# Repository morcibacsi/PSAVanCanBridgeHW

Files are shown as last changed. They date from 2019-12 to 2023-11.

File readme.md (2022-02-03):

# PSA VAN-CAN protocol bridge (hardware)

### What is it ?
This is the hardware needed for my PSA VAN-CAN protocol bridge software.

The files were created with KiCad. 

### v1.4

This is actually the sixth revision of the hardware (the fourth was faulty again and the fifth didn't make it to production).

It was designed as a shield for the ESP32 dev board. It uses the ESP32's RMT peripheral to read, the TSS463C to write the VAN bus and the CAN peripheral for connecting to the CAN bus. The CAN transceiver used on this board is the MCP2551.
The board was designed in a way that the LM7805 can be easily replaced by a step down converter shield.
To have an easier build I used a pre-built level shifter. I know it is not the best approach, but if I'd have it included on the board it would have been larger and much harder to build. My goal was to have a board which is easy to assemble.

I have included a buzzer and a DS18B20 thermometer on the board but they weren't ever tested if they work. I also included some spare connection points for later use.

If you are planning to build the board, go with the minimal setup. It is quite well tested, and is proven to work for years. The full board has never been tested. 

💡 **Make sure you don't populate R3 and R4 resistors as installing those cause errors in the car and the board won't work!**

### PCB

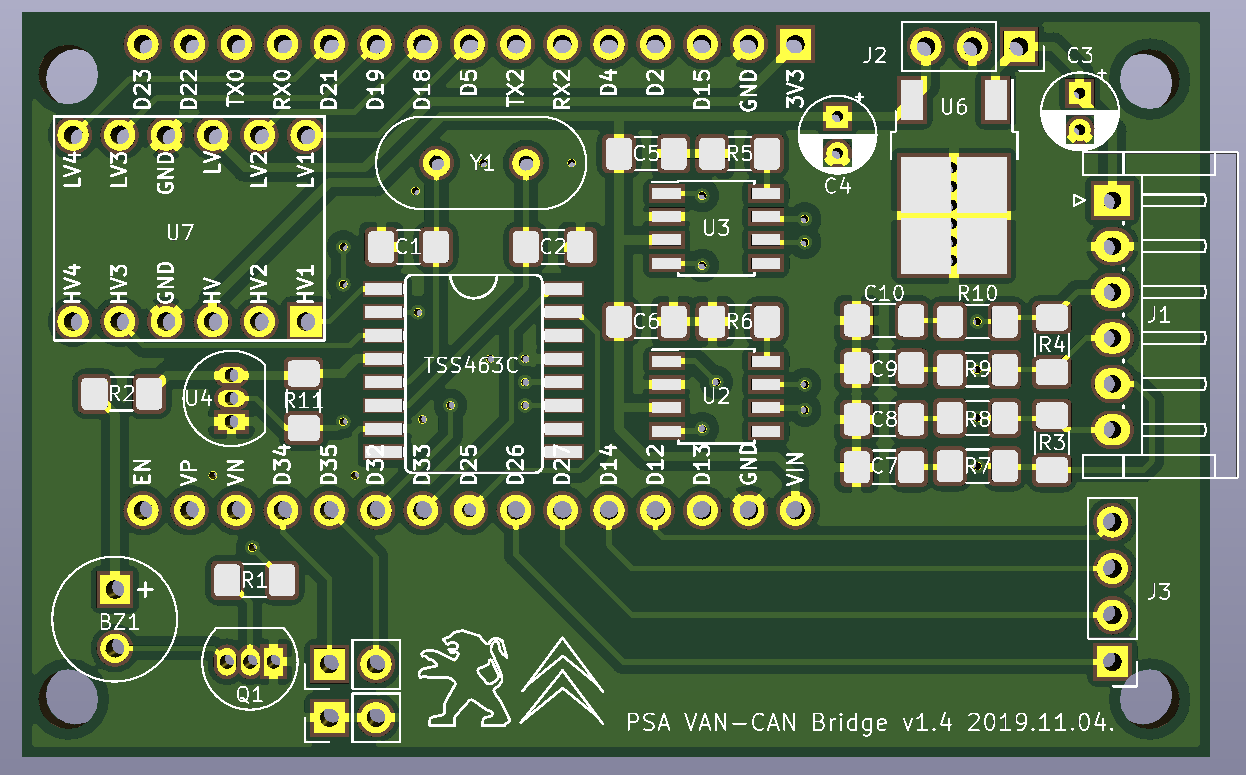
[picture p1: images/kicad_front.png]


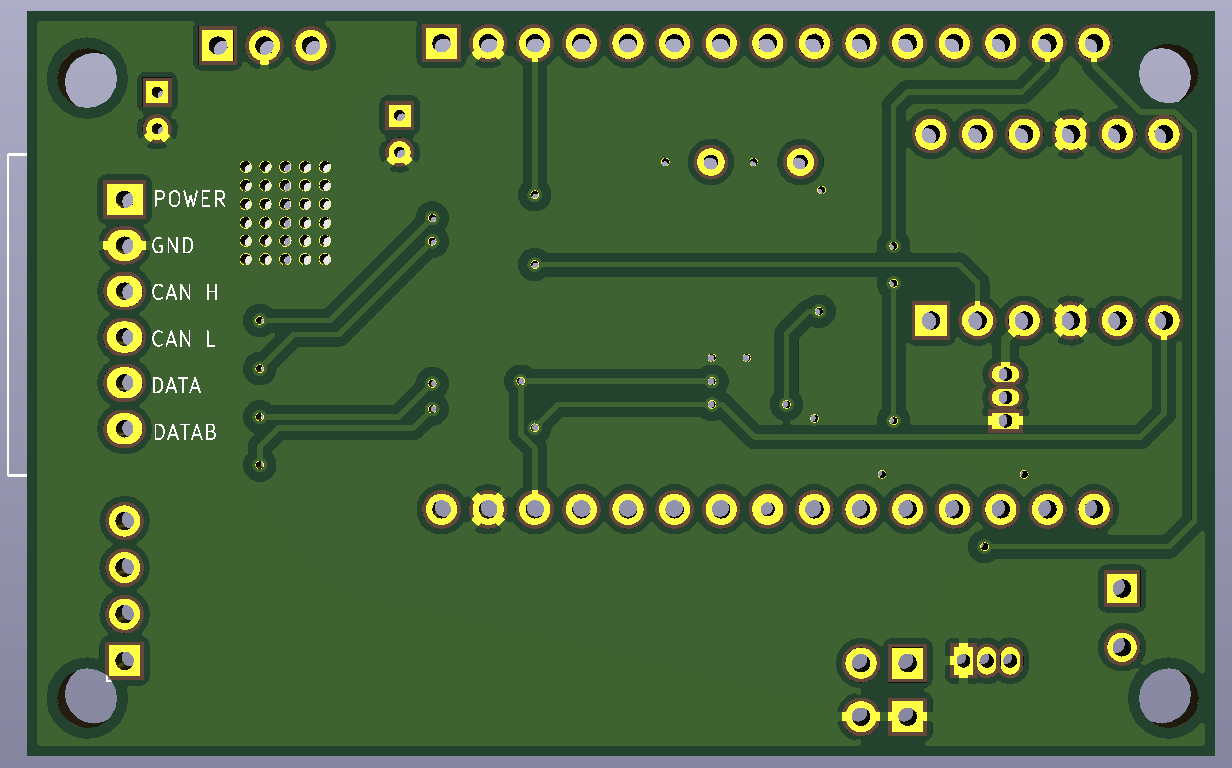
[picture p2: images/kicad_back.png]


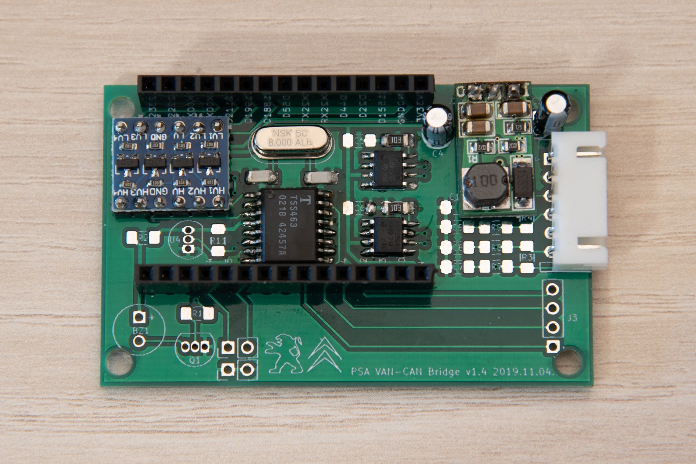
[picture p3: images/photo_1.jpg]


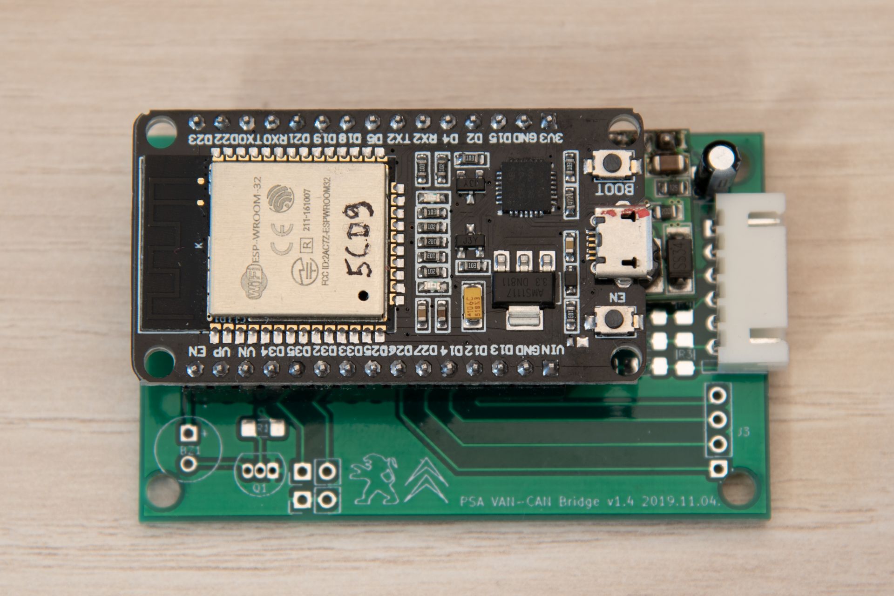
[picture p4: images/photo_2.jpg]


### BOM

### The absolute minimum to have it working:

| Ref | Quantity | Value |Footprint |
|-|-|-|-|
| C1 C2 | 2 | 22pF |Capacitor_SMD:C_1206_3216Metric_Pad1.42x1.75mm_HandSolder |
| C3 | 1 | 0.33uF |Capacitor_THT:CP_Radial_D4.0mm_P2.00mm |
| C4 | 1 | 0.1uF |Capacitor_THT:CP_Radial_D4.0mm_P2.00mm |
| Y1 | 1 | 8MHz |Crystal:Crystal_HC49-4H_Vertical |
| U1 | 1 | TSS463C |PSAVanCanBridge_v14:SO16L |
| U2 U3 | 2 | MCP2551-I-SN |Package_SO:SOIC-8_3.9x4.9mm_P1.27mm |
| U6 | 1 | LM7805_TO220 |Package_TO_SOT_SMD:TO-252-2 |
| U7 | 1 | LevelShifter4Shield |PSAVanCanBridge_v14:LevelShifter4_shield |
| R6 R5 | 2 | 10K |Resistor_SMD:R_1206_3216Metric_Pad1.42x1.75mm_HandSolder |
| J1 | 1 | Conn_01x06_Male |Connector_JST:JST_EH_S06B-EH_1x06_P2.50mm_Horizontal |

### The full board:

| | |
|-|-|
|Total Number of Parts | 36|
|Total Unique Parts | 22|

| Ref | Quantity | Value |Footprint |
|-|-|-|-|
| BZ1 | 1 | Buzzer |Buzzer_Beeper:MagneticBuzzer_Kingstate_KCG0601 |
| C1 C2 | 2 | 22pF |Capacitor_SMD:C_1206_3216Metric_Pad1.42x1.75mm_HandSolder |
| C3 | 1 | 0.33uF |Capacitor_THT:CP_Radial_D4.0mm_P2.00mm |
| C4 | 1 | 0.1uF |Capacitor_THT:CP_Radial_D4.0mm_P2.00mm |
| C6 C5 | 2 | 0.1uF |Capacitor_SMD:C_1206_3216Metric_Pad1.42x1.75mm_HandSolder |
| C8 C10 C7 C9 | 4 | 560pF |Capacitor_SMD:C_1206_3216Metric_Pad1.42x1.75mm_HandSolder |
| J1 | 1 | Conn_01x06_Male |Connector_JST:JST_EH_S06B-EH_1x06_P2.50mm_Horizontal |
| J2 | 1 | Conn_01x03_Male |Connector_PinSocket_2.54mm:PinSocket_1x03_P2.54mm_Vertical |
| J3 | 1 | Conn_01x04_Male |Connector_PinHeader_2.54mm:PinHeader_1x04_P2.54mm_Vertical |
| J4 J5 | 2 | Conn_01x02_Male |Connector_PinHeader_2.54mm:PinHeader_1x02_P2.54mm_Vertical |
| Q1 | 1 | PN2222A |Package_TO_SOT_THT:TO-92_Inline |
| R6 R5 | 2 | 10K |Resistor_SMD:R_1206_3216Metric_Pad1.42x1.75mm_HandSolder |
| R11 | 1 | 4.7K |Resistor_SMD:R_1206_3216Metric_Pad1.42x1.75mm_HandSolder |
| R3 R4 | 2 | 120 |Resistor_SMD:R_1206_3216Metric_Pad1.42x1.75mm_HandSolder |
| R2 R1 | 2 | 2.2K |Resistor_SMD:R_1206_3216Metric_Pad1.42x1.75mm_HandSolder |
| R8 R10 R7 R9 | 4 | 100 |Resistor_SMD:R_1206_3216Metric_Pad1.42x1.75mm_HandSolder |
| U1 | 1 | TSS463C |PSAVanCanBridge_v14:SO16L |
| U2 U3 | 2 | MCP2551-I-SN |Package_SO:SOIC-8_3.9x4.9mm_P1.27mm |
| U6 | 1 | LM7805_TO220 |Package_TO_SOT_SMD:TO-252-2 |
| U5 | 1 | ESP32 |PSAVanCanBridge_v14:ESP32_shield |
| U7 | 1 | LevelShifter4Shield |PSAVanCanBridge_v14:LevelShifter4_shield |
| U4 | 1 | DS18B20 |Package_TO_SOT_THT:TO-92_Inline |
| Y1 | 1 | 8MHz |Crystal:Crystal_HC49-4H_Vertical |

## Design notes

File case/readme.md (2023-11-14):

# PSA VAN-CAN protocol bridge (hardware) 3D printed case

### 3D printed case model
This is the 3D model for PSAVanCanBridge adapter in minimal hardware configuration.
Model contains two files:
- cap.stl
- body.stl

Cap is just press connection. For PCB mount I used M2.5x8 screws.

### Print details

I printed this on cheap chinese Ender 3 printer. Material is Devil Design PETG. Hotend temperature 230°C, table 70°C.

### Model look

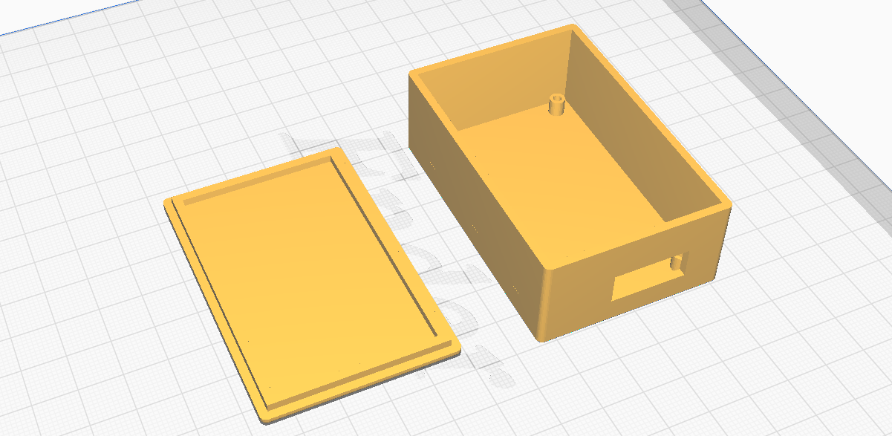
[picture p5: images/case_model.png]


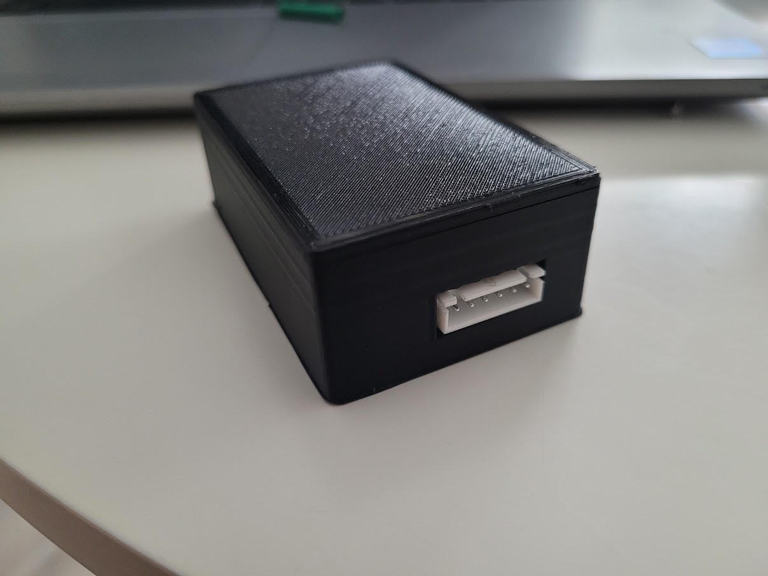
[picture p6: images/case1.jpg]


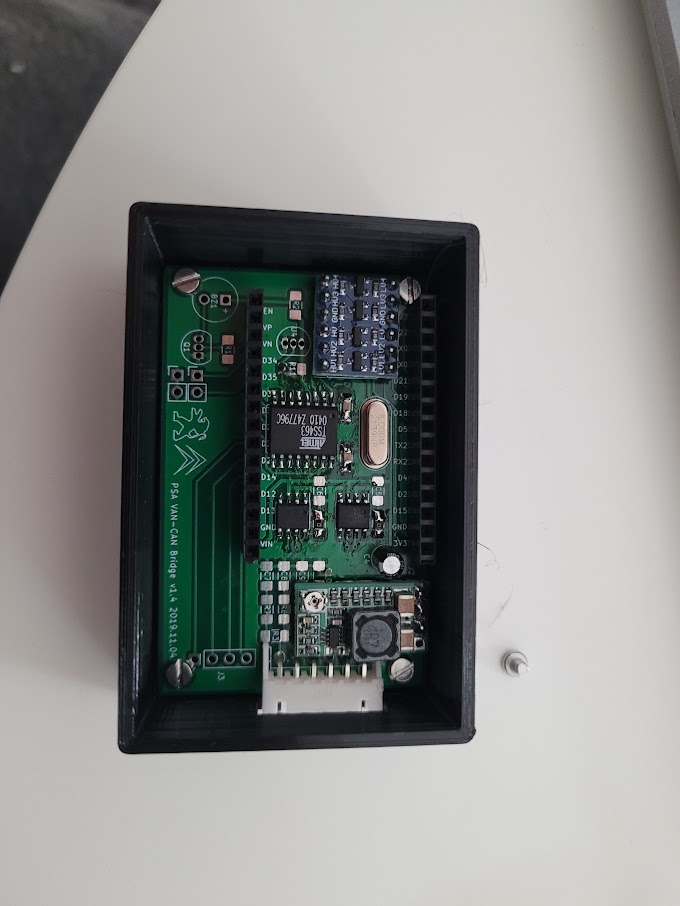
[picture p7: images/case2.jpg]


PS. It's simple case and my first CAD project. Hope someone will develop it ;)

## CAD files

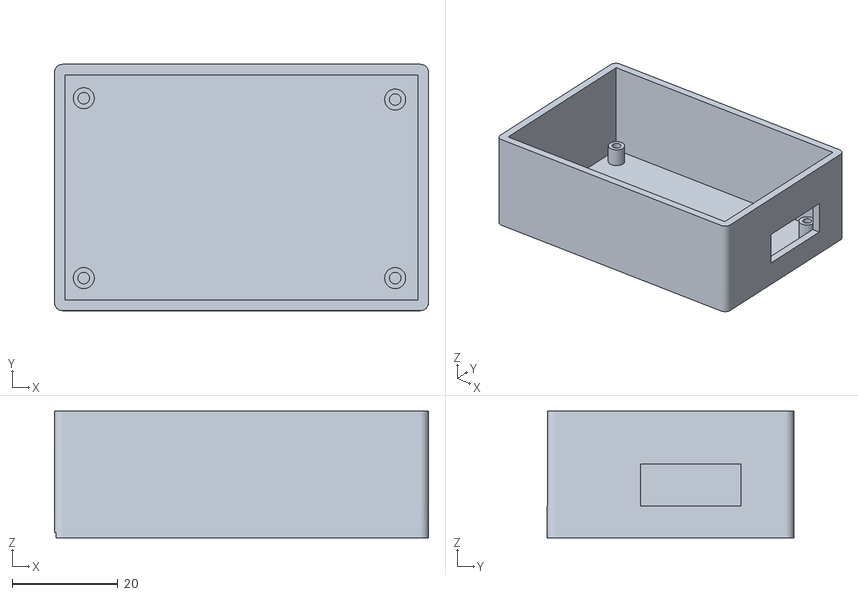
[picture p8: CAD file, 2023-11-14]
case/body.stl
70.8 x 46.6 x 24.0

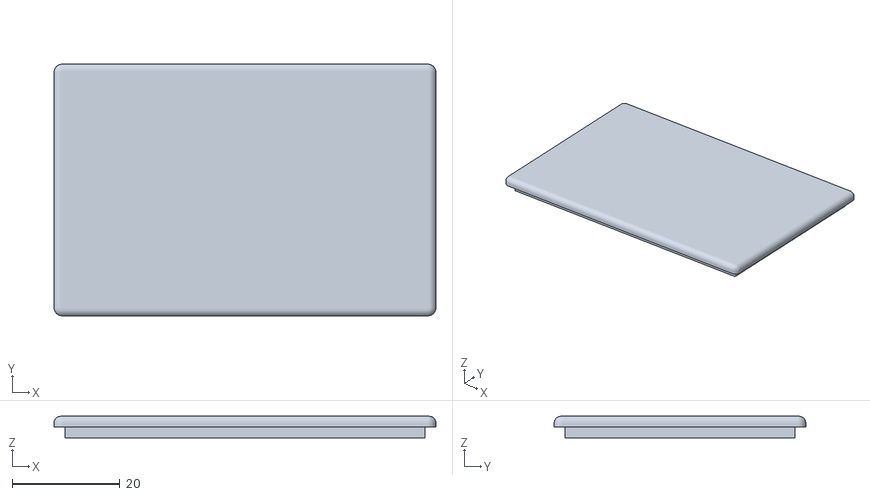
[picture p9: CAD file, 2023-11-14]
case/cap.stl
70.8 x 46.6 x 4.00

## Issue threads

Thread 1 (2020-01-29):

for better read/send message

unobayu, 2020-01-29:
after some trial. the hardware fail to read van bus data. also some problem (reboot) when send data. after measuring the data line in the car,there already have resistance. so i have to remove terminating resistor in the both tranceiver. now the hw11 is working good

morcibacsi, 2020-01-30:
Glad you make it work. I suggest to start with the setup what can be seen on the photos as I used it like that in my car. It is easier to add components later anyways than removing them.

DenGorobets, 2020-02-27:
Hi, can you answer a few questions?
I also have a VAN multimedia bus on my 2004 car. The head unit has a QUADLOCK connector (not ISO) and an on-board computer display with a 6-pin connector. I bought an Android device to replace the head unit, which in the kit has a Raise CAN emulator. When connected, of course, nothing works due to different buses. Will your device allow the full functioning of the Android device? And is it necessary to buy an on-board computer display that works on the CAN-bus?

morcibacsi, 2020-02-27:
@DenGorobets This means you have a monochrome RT3 navigation system. If you remove your original head unit, unfortunately that display will stop working. This is because those systems are a little bit funny: The RT3 communicates on the VAN bus however the display has a CAN bus connection towards the head unit. So the RT3 is translating the VAN bus packets for the display. But reverse engineering the CAN communication for that display would be a pain (I've tried it, but it just doesn't worth the effort). So in my opinion it is easier to just replace the display with a newer one. The navigation part would stop working anyways without the RT3. I assume you would like to keep the remote stalk function for your new Android head unit. My device is capable of translating the VAN bus packet of the remote stalk to the corresponding CAN packet. So if you would set the correct car type (Peugeot with CAN bus) in your Android system then most probably it would work.

DenGorobets, 2020-02-27:
Thank you for the explanation. Android device does not start when the ignition is turned on. If I understand correctly, it’s all because the CAN emulator does not understand that when you turn the key on the VAN bus, a command is sent to turn on the head unit, which the emulator does not understand.
Based on your answer, it is possible without using your development to connect the on-board computer display from the Peugeot 407, which will be controlled by the CAN emulator of the Android device. Right?

morcibacsi, 2020-02-27:
> Android device does not start when the ignition is turned on

Well that is another problem then. These aftermarket devices don't need ignition signal to work. If you connect to a power supply it should even turn on outside a car. What is the exact model number of the device?

> Based on your answer, it is possible without using your development to connect the on-board computer display from the Peugeot 407, which will be controlled by the CAN emulator of the Android device. Right?

Not quite. If you would like to install a display from a 407 then you definitely need my VAN-CAN bridge. The CAN device inside the Android head units don't send the data for those displays to boot up.

DenGorobets, 2020-02-27:
There is no exact name, I bought it at this link: https://aliexpress.ru/item/33035372080.html?spm

There are two connection cables in the kit: from ISO to 16 pin in an Android device, from QUADLOCK to 16 pin in an Android device.
In both cases, there are three wires to power the device: black - ground, yellow - permanent + 12V and red - when applying + 12V to the red wire, the device starts up (if you remove the device from the red + 12V, it falls asleep after 30 seconds).
In the adapter with ISO, the red cable is connected directly to the Android device.
In the adapter with QUADLOCK, the red cable is connected from the CAN emulator to the Android device.
Based on this, I suggested that it is the KAN emulator that launches the Android device when the ignition is turned on.

I do not exclude the option that the emulator is not working, there is no way to check it.

morcibacsi, 2020-02-27:
I see now. That quadlock connector you got with your Android device is for cars made after 2005 with CAN bus. In those cars there is no switched 12V in the quadlock connector, so most probably in those cars ignition signal from the CAN bus is used to turn on the device. For you the simplest thing would be to connect the red cable to the VAN+ pin which is I believe the A9 pin on the quadlock. That way your android unit would boot up when you open the car. And would go to sleep after a few minutes when you close it.

DenGorobets, 2020-02-27:
This is a great option for the first time. Thank you so much for the consultation!

Closed 2020-02-28.

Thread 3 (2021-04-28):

Bonjour

Mokrane82, 2021-04-28:
J'ai peugeot 307 année 2005 commande au volant autoradio RT3 VAN
J'ai acheté un autoradio android junsun 2G 32G B commande au volant.
J'ai utilisé 4 CANBUS
Mais il fonctionne pas

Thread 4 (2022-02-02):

Wont turn on. Issue with termination resistors

najdanovicivan, 2022-02-02:
When 120 ohm termination resistors are present on ether CAN or VAN line things will not work

VAN issue - The instrument gauge started to flicker all indicators turns on same way like the VAN line is disconnected
CAN issue - The screen does not turn on and RD45 will just spin CD motor for a fraction of second and this will happen in loop

I resolved the issue by removing  R3 and R4 resistors.

Tested with RD45 on 206CC

morcibacsi, 2022-02-03:
Thanks for reporting. It was known before, I just forgot to update the readme with the information. Added a warning in 14ef456b4231d8f84fe3717f5a421d99a402b76a

Closed 2022-02-03.

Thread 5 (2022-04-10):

CAN-converter?

WildeRNS, 2022-04-10:
Thanks for you work. Want to make such device but have question: can I use SPI - CAN converter (MCP2515 and TJA1050)?: https://images.prom.ua/2447555310_w600_h600_2447555310.jpg
or:
https://images.prom.ua/2772277826_w640_h640_mcp2551-vysokoskorostnoj-high-speed.jpg
Thanks

WildeRNS, 2022-04-11:
I have Peugeot 206 plus car and android head unit. I want to replace my original display with android (include can-bus adapter), so I don't need to send van-packages, only receive (e.g.: information such as opened doors, turned lights, and so on).

morcibacsi, 2022-04-15:
Well... if you wish to remove the original display from the car, then you need to send packets on the VAN bus, because for some data the display is the initiator of the data-exchange. The fuel consumption data, and the door open statuses is such a message (they are both in the same data frame). So if you remove the original display, there will be nothing to initiate the data transfer, so the data won't be there on the bus (so nothing to receive).
So if you can't obtain a TSS463, then you need to keep your original display (reroute its wiring to the glovebox, or somewhere below the dashboard). In this case you can get away with my v1.1 bridge which can receive the frames (but that can't send).

mbprado, 2022-11-03:
To add some light to someone who has troubles finding TSS463: it can be found inside RD3 radios and can be bought practically everywhere for few bucks...

karolp1993, 2023-11-14:
> To add some light to someone who has troubles finding TSS463: it can be found inside RD3 radios and can be bought practically everywhere for few bucks...

Or in even cheaper 307 instrument cluster ;)

BatmanJMF, 2023-12-28:
hello,
I am a novice for the PSA VAN-CAN protocol bridge what is ESP32 used for?

Best regards.

morcibacsi, 2023-12-28:
> hello, I am a novice for the PSA VAN-CAN protocol bridge what is ESP32 used for?
>
> Best regards.

The ESP32 board has the microcontroller which contains the software used to translate the VAN bus messages to CAN.

BatmanJMF, 2023-12-28:
hello,
If I understand correctly the card cannot work without ESP 32?
In fact I have a car in VAN protocol with a car radio that I changed with a tablet which has a CanBus box.
My dashboard is a Christmas tree.
I wanted to put this box to translate the VAN protocol into CAN.

Best regards,

karolp1993, 2023-12-28:
ESP32 is mandatory. Is main processing unit in this board. If you have some aftermarket radio with CANbox dedicated to Peugeot with CAN bus, you can connect Peter's adapter to canbox adapter and it should work.

BatmanJMF, 2023-12-28:
Sorry,
what is the adapter Peter?
I can't find it on the internet.

Best regards,

karolp1993, 2023-12-28:
Peter's adapter I mean this VAN-CAN adapter

BatmanJMF, 2023-12-31:
Good morning,
I'm still looking for a solution for my tablet problem on my 307CC.
I would like to make your Can Van adapter "PSAVanCanBridge".
I don't think I have any problem making your Can Van adapter "PSAVanCanBridge"(hardware).
On the other hand, I have been trying for two days to compile your program for the ESP 32 and I am encountering a problem with the "BluetoothSerial.cpp" file, it is giving me errors.
I downloaded the latest versions of the "PSAVanCanBridge" file.
I have a
[Erreur.txt](https://github.com/morcibacsi/PSAVanCanBridgeHW/files/13801419/Erreur.txt)
little notion of programming but that is well beyond my skills.
I'm attach the Arduino error message.
Can you help me ?
THANKS.

BatmanJMF, 2023-12-31:
Good morning,
I'm still looking for a solution for my tablet problem on my 307CC.
I would like to make your Can Van adapter "PSAVanCanBridge".
I don't think I have any problem making your Can Van adapter "PSAVanCanBridge"(hardware).
On the other hand, I have been trying for two days to compile your program for the ESP 32 and I am encountering a problem with the "BluetoothSerial.cpp" file, it is giving me errors.
I downloaded the latest versions of the "PSAVanCanBridge" file.
I have a little notion of programming but that is well beyond my skills.
I'm attach the Arduino error message.
Can you help me ?
Thanks
[Erreur.txt](https://github.com/morcibacsi/PSAVanCanBridgeHW/files/13801423/Erreur.txt)
.

morcibacsi, 2023-12-31:
Please compile it using platformio. There are so many versions of the esp32 platform and the required libraries that it is impossible to support compiling from Arduino.

karolp1993, 2023-12-31:
And use main, not master branch

BatmanJMF, 2023-12-31:
In the file "VanMessageReaderEsp32Rmt"  I had 4 errors:

1: [Ln 22, col 16] "_van_rx = new ESP32_RMT_VAN_RX(VAN_DATA_RX_RMT_CHANNEL, rxPin, ledPin, static_cast<VAN_LINE_LEVEL>(vanLineLevel), static_cast<VAN_NETWORK_TYPE>(vanNetworkType));"
     I changed to: "_van_rx = new ESP32_RMT_VAN_RX();"

2: [Ln 27, col 18] "_van_rx->ReceiveData(messageLength, message);"
     I changed to: "_van_rx->Receive(messageLength, message);"

3: [Ln 32, col 18] "_van_rx->Start();"
     I changed to: "_van_rx->~ESP32_RMT_VAN_RX();"

4: [Ln 37, col 23] "_van_rx->Stop();"
     I changed to: "_van_rx->Stop(VAN_DATA_RX_RMT_CHANNEL);"

Can you tell me if these changes are correct?

Thanks,

BatmanJMF, 2024-01-01:
Hello,
Thanks for your help I was finally able to compile the program.
Happy New Year everyone.

BatmanJMF, 2024-03-01:
Bonjour,
J'ai enfin eu le temps de fabriquer le PSAVanCanBridgeHW-1.4 et je l'ai interfacé avec le boitier canbus fournir avec la tablette et pour l'instant ca fonctionne sans faire planter mon tableau de bord.
Je voulais vous remercier pour votre aide elle ma été d'une grande utilité.
J'ai pris la version simple du PSAVanCanBridgeHW-1.4 et j'aimerais encore essayer de réduire ca taille car ca me fait deux boitier a garder.
Pour cela je voulais savoir si il était possible de remplacer les deux MCP 2551 avec par exemple un MCP25612FD-E/SL ?
Et si on pouvais remplacer la carte électronique ESP32 par simplement le circuit intégrer ESP32-U4WDH en la programment avec un convertisseur USB?

karolp1993, 2024-03-02:
Should be doable.

morcibacsi, 2024-03-02:
It is possible to use that CAN transceiver. Version 1.4 of the board was designed with components which are easy to obtain, and easy to solder by hand. But this way it is fairly large. Actually it is stuck in kind of a prototype phase. I have a similar project which is a dual-CAN board here: [PSACANBridge](https://github.com/morcibacsi/PSACANBridgeHW/tree/v1.4)

Based on that board I am in the middle of redesigning the VAN-CAN bridge board. It will look very similar to this:

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
BatmanJMF, 2024-04-06:
Bonjour,
J'ai installé l'esp32-S3 sur le PCB PSAVANCANBRIDGE en mettant "board = esp32-s3-devkitc-1" et réaffecter les pins dans le programme.
Le programme se téléverse bien mais ca ne fonctionne pas avec la tablette alors que ca fonctionne avec la carte DOIT ESP32 DEVKIT V1.
Quand je branche ma carte esp32-S3 dans arduino il me dit que c'est une carte "TAMC Termod S3".
J'ai changé les paramètres dans le fichier platformio.ini et là il me met une erreur à la compilation.
Est ce important de mettre "board = TAMC Termod S3" au lieu de "board = esp32-s3-devkitc-1" et est ce que c'est ça qui fait que ca fonctionne pas avec ma tablette ?

morcibacsi, 2024-04-07:
I am not familiar with that board, and you didn't mentioned what kind of errors do you have. But after a quick google search I found this: [https://docs.platformio.org/en/stable/boards/espressif32/tamc_termod_s3.html](https://docs.platformio.org/en/stable/boards/espressif32/tamc_termod_s3.html) which mentions that in the board you need to set **tamc_termod_s3** However take note even if you set the correct board type, you might face some other compiler errors as the esp framework is constantly changing and for new boards there might be other adjustments needed (for example for my CAN2004 - CAN2010 bridge using the esp32-c3 I needed to modify the ESP CAN driver to include twai.h instead of can.h and make some other adjustments since they renamed a few things)

BatmanJMF, 2024-04-07:
Bonjour,
Je connais ce lien et j'ai effectué les modifications dans le fichier platformio.ini.
Je sais pas si vous pourrez me répondre mais qu'est ce qui détermine que le modèle de ESP32-S3 on à.
Sur le site expressif il y a plein de ESP32-S3 Example "tamc_termod_s3", Espressif ESP32-S3-DevKitM-1, DFRobot Roméo ESP32-S3?
je vous joins le message d'erreur que j'ai quand compile le programme avec "tamc_termod_s3"
[Erreur.txt](https://github.com/morcibacsi/PSAVanCanBridgeHW/files/14897374/Erreur.txt)

morcibacsi, 2024-04-07:
I created a new branch: [https://github.com/morcibacsi/PSAVanCanBridge/tree/multi_board_support](https://github.com/morcibacsi/PSAVanCanBridge/tree/multi_board_support)

You can set the target type in platformio.ini by commenting and removing the comment on lines 14 and 15.
[https://github.com/morcibacsi/PSAVanCanBridge/blob/multi_board_support/platformio.ini#L14](https://github.com/morcibacsi/PSAVanCanBridge/blob/multi_board_support/platformio.ini#L14)

After that you need to modify BoardConfig_ESP32_tamc_termod_s3.h file according to your pin setup.
[https://github.com/morcibacsi/PSAVanCanBridge/blob/multi_board_support/PSAVanCanBridge/BoardConfig_ESP32_tamc_termod_s3.h](https://github.com/morcibacsi/PSAVanCanBridge/blob/multi_board_support/PSAVanCanBridge/BoardConfig_ESP32_tamc_termod_s3.h)

BatmanJMF, 2024-04-10:
Bonjour,
J'ai téléversé votre nouveau programme dans l'ESP32-S3 sans aucun problème.
Malheureusement ca ne pilote pas ma tablette.
J'ai téléversé votre nouveau programme dans esp32doit-devkit-v1 et malheureusement ca ne fonctionne pas non plus avec ma tablette.
Savez vous pourquoi ?
Je vous joins un message d'alerte dans le programme mais je pense pas que le problème vienne de la.
[Message d'alerte.txt](https://github.com/morcibacsi/PSAVanCanBridgeHW/files/14936396/Message.d.alerte.txt)

romawkafor, 2024-05-03:
Hello, I am planning to make a v1.4 board, but unfortunately we do not have a place to buy a controller in Ukraine: TSS463C.  Can I use a version 1.1 board and what will I run into if I use an older version?

Thank you Advance for your Replay.

karolp1993, 2024-05-03:
> Hello, I am planning to make a v1.4 board, but unfortunately we do not have a place to buy a controller in Ukraine: TSS463C. Can I use a version 1.1 board and what will I run into if I use an older version?
>
> Thank you Advance for your Replay.

You can get TSS463C from cluster or central display

romawkafor, 2024-05-08:
@morcibacsi Thank you for the honor of receiving your reply. In my opinion, you have done a great job and also shared it with the community. Thank you for that. I found this chip on taobao.com. Awaiting delivery. True, there are several modifications: TSS463, TSS463**C**, TSS463**C-E9**. I couldn't find a document describing the differences, but I ordered one like yours, **TSS463**.

BatmanJMF, 2024-07-31:
@morcibacsi
Bonjour,
j'ai lu sur un autre post du forum que dans le fichier config.h il fallait inscrire le VIN du véhicule.
Je voulais savoir si c'est toujours d'actualité sur la version 1.4 du PSAVANCANBRIDGE ?
Merci

morcibacsi, 2024-08-01:
@BatmanJMF
If you use the main branch of the software, it has a captive portal where you can set the VIN.

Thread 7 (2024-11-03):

Custom SPI shield repository link

marimbando, 2024-11-03:
Hello morcibacsi,
Thank you very much for you work. I've ordered and I am currently waiting for your new interface PSAVanCanBridgeHW v1.5, but I would like to use the SPI shield with the TSS463. However the link for the repository of the SPI shield is not working. Is it possible to post the KiCad or gerber files so that I can order the PCB?

morcibacsi, 2024-11-11:
Uploaded the files to that repository.

I haven't tested the TSS463 side of that board, because the new board (1.5) can write the VAN bus safely purely from software. I am using it without the TSS463 in my 307 and everything seems to be fine. But if you build it please let me know if it works.

marimbando, 2025-02-15:
Hello again morcibacsi,
I've built 3 interfaces with the TSS463 and 2 without. The interfaces with the TSS463 don't show the warning messages like when I open a door and also the button of the trip computer seems not being recognised. I've tried to connect to the bluetooth serial to debug, but when I make a bluetooth device search with my smartphone, I can't find the interface. Do I have to change anything in the configuration files before compiling?

morcibacsi, 2025-02-17:
> Do I have to change anything in the configuration files before compiling?

Yes, if you have the TSS463 installed on your board then you need to setup the solder jumpers accordingly:

_If you would like to use the SPI shield with the TSS463 the jumper marked with red rectangle on the back (2) must be closed to 5V._

And also need to set BOARD_ULP_VAN_TX_ENABLED to false in BoardConfig_ESP32_v15.h:
https://github.com/morcibacsi/PSAVanCanBridge/blob/main/PSAVanCanBridge/BoardConfig_ESP32_v15.h#L22

marimbando, 2025-03-01:
I've verified the setup of the jumpers and all is correctly set.
When I set
BOARD_ULP_VAN_TX_ENABLED to false in BoardConfig_ESP32_v15.h, it gives me a compiling error in VanWriterTask.cpp:
https://github.com/morcibacsi/PSAVanCanBridge/blob/main/PSAVanCanBridge/src/Van/VanWriterTask.cpp#L20
To compile, I've changed the expression "#elif" to "#else".
I've also commented out line 8 of the same file to exclude "VanMessage SenderUlp.h".
Even with all modifications, it seems that the PSAVanCanBrigeHW reads the VAN bus but doesn't write to it.
Is there a way to verify if the hardware is correctly sending data to the VAN bus?

morcibacsi, 2025-03-02:
> I've verified the setup of the jumpers and all is correctly set. When I set BOARD_ULP_VAN_TX_ENABLED to false in BoardConfig_ESP32_v15.h, it gives me a compiling error in VanWriterTask.cpp: https://github.com/morcibacsi/PSAVanCanBridge/blob/main/PSAVanCanBridge/src/Van/VanWriterTask.cpp#L20 To compile, I've changed the expression "#elif" to "#else".

Right, that is a typo, thanks.

> I've also commented out line 8 of the same file to exclude "VanMessage SenderUlp.h".

If you are compiling for ESP32 (and not ESP32 S3, or any newer boards) it can stay.

> Is there a way to verify if the hardware is correctly sending data to the VAN bus?
If you can see the consumption data, and can switch between them, and can see on the display which door is open, then the board writes to the VAN bus. If these don't work then something is wrong with writing to the bus.

Is there any reason why you are trying with the SPI shield? With the other setup (ULP VAN writing) it should work.

marimbando, 2025-03-02:
I'm trying to build the PSAVanCanBridge with the SPI because I have an EMF type C with A/C unit display support so I wanted to enable the option QUERY_AC_STATUS but, to enable that option, it says that I need a rev 1.4 interface.
Do I really need to have a rev 1.4 interface to use that option or do a rev 1.5 interface with the TSS463 SPI shield would work?

morcibacsi, 2025-03-03:
Ah I see. It should work without the TSS463 with the 1.5 board, although I never tested it. The documentation was written before 1.5 existed. Note that when QUERY_AC_STATUS is enabled then the AC will execute an initialization sequence of the flap-motors which makes a strange noise on startup.

marimbando, 2025-03-03:
I thought that the TSS463 was absolutely necessary to have the QUERY_AC_STATUS enabled. I will try to enable it tomorrow on the interface without the TSS463 to see what happens. Thank you very much for your help.

marimbando, 2025-03-06:
I have enabled the QUERY_AC_STATUS but there is no additional info in the EMF neither strange noises from the flap-motors. Is it possible to see if theres a difference between the QUERY_AC_STATUS enabled and disabled through the serial interface?

marimbando, 2025-03-13:
I have finally found the reason why the TSS463 didn't worked on the 1.5 board. The C4, C5 and C6 of the SPI shield are connected to MOSI instead of being grounded. I soldered 2 wires and cuted the tracks to modify the SPI shield and now it works. However, I still don't have any infos on the EMF regarding the A/C flap-motors positions. Did you had such infos on your 307 with the 1.4 board?

morcibacsi, 2025-03-14:
> The C4, C5 and C6 of the SPI shield are connected to MOSI instead of being grounded

Damn, you are right! I don't know how I missed that. Thanks for the investigation, I'll update the repository.

> However, I still don't have any infos on the EMF regarding the A/C flap-motors positions. Did you had such infos on your 307 with the 1.4 board?

Yes, with 1.4 it was working. I will try to check in the following days if it is a software issue with the latest code.

Btw what type of car do you have? It has an automatic A/C, right?

marimbando, 2025-03-14:
> Yes, with 1.4 it was working. I will try to check in the following days if it is a software issue with the latest code.

I have compiled the software in the master repository with the necessary pin number changes to the v1.5 board and I have the temperature info, although it seems not very accurate, but I still don't have the positions infos.

> Btw what type of car do you have? It has an automatic A/C, right?

I have a 307 SW and yes, it has an auto A/C.

marimbando, 2025-03-19:
> Ah I see. It should work without the TSS463 with the 1.5 board, although I never tested it.

I've read the serial output of both v1.5 interfaces, one with and another without the TSS463 chip,  both programmed with the main branch. On the interface without the chip, the A/C diagnostic frames beginning with A5C are sent a lot less frequently than the interface with the chip. Also, the chipless version receives the frames regarding the A/C unit diagnostic (beginning with ADC) but never the ones that have informations regarding the sensors (C0) neither the actuators (C1).

In the version with the chip I receive the frames with all the A/C unit diagnostic informations, but it doesn't show any of them on the display like I managed to achieve with one programmed with the master branch. I've tried to search what may be missing in the main branch by comparing with the master branch but, since I've never coded neither learned how to, I'm completely lost. 😅
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
marimbando, 2025-04-05:
@morcibacsi

I didn't have much time this last week but, from what I could test, it works well even without the TSS463. However, in this main branch, the info of the internal temperature is not showed like it was on the master branch. I see that the VAN frames regarding the internal temperature are received by the interface but they aren't being processed or, at least, they are not showing in the EMF. What would be needed in order to implement it?

morcibacsi, 2025-04-06:
I didn't add it, because the diagnostic message contains the real internal temperature not the desired temperature you set on your A/C. Unfortunately the CAN screen only shows values between 11 an 25 °C and anything outside of that range will get displayed as Min or Max. So it is kind-of useless. If it doesn't bother you I can add the feature back in the following days. Btw thanks for testing!

Chaozzmax, 2025-04-20:
Wow,
there is an update for the hardware to v1.5,
sorry I also commented here, from what I read for v1.5 there is no need for the TSS463 IC (i really hard to find this IC on my c9untry) which is placed on a separate SPI shield and is located under the main PCB
Is that right?

morcibacsi, 2025-04-22:
> Wow, there is an update for the hardware to v1.5, sorry I also commented here, from what I read for v1.5 there is no need for the TSS463 IC (i really hard to find this IC on my c9untry) which is placed on a separate SPI shield and is located under the main PCB Is that right?

With the v1.5 board, you don't need the TSS463 anymore—it works without it. Actually, the SPI shield was added for two reasons:
* To have a fallback in case it didn’t work without the TSS463 (I wasn’t sure how reliable it would be before building the board and testing it in a real car)
* To support my other project for AEE2004 → AEE2010 conversion, where I need to connect to two CAN buses simultaneously

marimbando, 2025-07-06:
Hi morcibacsi,

I've been testing my v1.5 board without the TSS463 with the main branch software for the last 3 months and it's working perfectly. However,  I would really like to have the EMF to display the interior temperature, if possible. Do you think that it's needed a lot of code changes to make it work?

I've also seen that there is a new hardware and software versions. Does the v1.5 board may be programmed with the v3 software?

Thanks for your work and for all your help. It's really cool to have unique mods like this in our cars and, at the same time, learn something new everyday.

marimbando, 2025-07-10:
> The temperature you set on your A/C isn't distributed on the VAN bus, so there is no way to display that. The real internal temperature can be queried by a diagnostic message, but as I wrote previously: Unfortunately the CAN screen only shows values between 11 an 25 °C and anything outside of that range will get displayed as Min or Max. If you are fine with this solution, I try to find some time to add the feature.

It's fine by me that way. For me, it's better than having "Min" displayed all the time. If you could add that feature I would really be grateful. Maybe with an option in config to deactivate the feature to those that don't want it.

> The branch v3 currently doesn't support the v1.5 board, but there is a plan to add support for it. Also currently there is no real benefit to switch to the v3 version as it is in early stage. Btw the main branch was renamed to v2 (in case you are looking for that branch)

From what I understood, the advantage of the v1.6 board is that it can make AEE2004 -> AEE2010 translation and also of VAN protocol to any of the CAN protocols without having to change the software (v3) and without the need of the SPI shield, right?

morcibacsi, 2025-07-12:
> It's fine by me that way. For me, it's better than having "Min" displayed all the time. If you could add that feature I would really be grateful. Maybe with an option in config to deactivate the feature to those that don't want it.

I'll try to update it in the next week.

> From what I understood, the advantage of the v1.6 board is that it can make AEE2004 -> AEE2010 translation and also of VAN protocol to any of the CAN protocols without having to change the software (v3) and without the need of the SPI shield, right?

Yes, exactly. The v3 (and the v1.6 board) is to have a unified hardware and software which enables translating between VAN-CAN and CAN-CAN. Also the aim was to simplify the hardware to require as few components as possible.

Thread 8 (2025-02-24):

TSS461 in intel mode instead of TSS463 ?

godlespawel1, 2025-02-24:
Hello, I have a question. Is it possible to replace TSS463 with TSS461? This is about rev 1.4. I would like to connect it in INTEL mode. Any tips?. It's about config in the code, can it be done easily? There should be enough pins. I have several pieces of TSS461 and 463 is practically unavailable. Or maybe it's not needed at all? I have already built rev 1.1 with the original display in the glovebox. It operated for several years, but the weather took its toll and it began to deteriorate. I'm wondering if I'll gain anything by building a 1.4 instead of a 1.1 Peugeot 607 2003 with the original EMF-C Siemens monochrome with GPS.

morcibacsi, 2025-02-25:
Hi,

If you need to build one I suggest the 1.5 board as it has a much better voltage regulator circuit. Version 1.1 and 1.4 can overheat which can make them unstable. If you would like to stick with the 1.4 then I attached a picture where I marked the pads to connect which converts the board to 1.5. This way you don't need the TSS463 as the board itself is capable to write on the VAN bus from software. In this case the software from the **main** branch must be used.

In theory TSS461 could be also utilized but that needs a completely different board. In that case the TSS library should be initialized like this: https://github.com/morcibacsi/arduino_tss463_van?tab=readme-ov-file#tss461
I never tested it with an ESP32 though. (it works with the STM32 BluePill so it should be ok with the ESP32 as well since the library is Arduino based)

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

godlespawel1, 2025-02-25:
Thanks for your reply! Yours means that when converting as in your photo, basically all the work is done by ESP32 and two transceivers, everything is done by software, right? SN65hvd230 will be ok? So, in version 1.5, what is the function of spi shield?

morcibacsi, 2025-02-25:
Exactly, with the above modification everything is done by software. SN65HVD230 might work, but I don't have good experience with those (too many faulty chips). MCP2551 and TJA1040/TJA1042/TJA1050 are much reliable. The SPI shield was added to have a plan B if the pure software solution wouldn't work. Also with the SPI shield I can add a second CAN interface so it makes the board more flexible. With the latest software hopefully you won't need the original display connected.*

*Except in some rare cases, but in that case the TSS also doesn't help. In some Peugeot 206 (and Citroen C2) there is a weird bug which makes the BSI crash. See this issue: https://github.com/morcibacsi/PSAVanCanBridge/issues/34 I couldn't figure out the root cause of this so far. In this case the VAN bus writing can be disabled in the software and you can still fall back to have the original display connected to somewhere hidden.

godlespawel1, 2025-02-25:
D33 and D21 connected to each other to VAN RX, i.e. pin 1 of the transceiver, and D32 to VAN TX, pin 4 of the transceiver? Can I see correctly? Actually, I might as well build v1.5. RTC is necessary for operation in 1.5 ?

morcibacsi, 2025-02-25:
Right, D21 also connected to VAN RX, shouldn't matter. Also VAN TX is connected to D13 and D32... that also shouldn't matter, but to be on the safe side you can cut those traces (D21 and D13) if you like. RTC is not necessary for VAN->CAN conversion, in fact currently it isn't even supported. It is there for my CAN2004->CAN2010 converter software. I recommend to build v1.5 if you can.

Or... if you are patient enough I have a new revision in the works. It will use an ESP32-C6 micro board. It looks like this. I am currently writing the software for it. Looks very similar to V1.5, but cheaper as it doesn't require as many components and also easier to flash the software as the ESP32-C6 has an USB port. It also contains the RTC circuit but it also isn't required. The picture contains the level shifter circuit as well, but that also isn't required.

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

morcibacsi, 2025-02-26:
Currently not planning to support the ESP32-S3. In theory the software should work with it, but the pinout of the S3 is most probably different. I attach a picture of the C6 I am using.

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

What kind of display do you mean by non-standard screens? Do you have any specific version to suggest?
I am aware of the issues of the GPS version, I was planning to create something similar like this, but it won't be happening in the near future for sure: https://github.com/hackingchips/Peugeot-3008-Display also not sure which display should I choose. The dimensions of the original display is quite unique so it's difficult to find a suitable replacement.

godlespawel1, 2025-02-26:
I am especially thinking about the 18-pin Siemens displays. They are particularly hard to find and I have never personally seen them display all the lines without a problem. Much more functions than the standard and most common Sagem. There were many variations of this screen, both with and without GPS. It was basically a small on-board computer, headlight discharge settings, rain sensors or automatic lights. Unfortunately, as I mentioned, I have never seen one that is fully functional, which is a shame because these cars are slowly becoming cool youngtimers. One of the numbers is 96312345ZL, S110661004, 96441322ZL, 96374118ZL. Unfortunately, the sticker on mine has worn off. I know that there were versions with the option of connecting an external GPS module. I know that variations of this screen were also installed in 206 mux, in late 406, 807, xsara, c8, c5 phase 1. Unlike the orange ones in Peugeots, Citroen had them in the version with a green screen color and also in the GPS version. Today they are useless, but for fun and as a curiosity. The photos of the motherboard are from my screen, 607 3.0 z8 2003. I am also pasting a link to the archive of a great website from which I got a lot of information, unfortunately the website has been inactive for several years but fortunately it seems to be completely on wayback, sometimes you have to change the date to get to some categories. Lots of descriptions, types of connectors, photos. https://web.archive.org/web/20170519155301fw_/http://elektron.pol.lublin.pl/users/djlj24/studio24/kable/dolkab.htm

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

bronisMateusz, 2025-02-26:
@godlespawel1 Once, looking for information on how to resurrect my Type C display from a Peugeot 206, I came across this repository: [https://github.com/0xCAFEDECAF/VanLiveConnect](https://github.com/0xCAFEDECAF/VanLiveConnect)

The screen has been replaced by a phone, the reading of the navigation directions works. However, it is not aesthetically ideal as it does not look like the factory solution.

godlespawel1, 2025-02-26:
@bronisMateusz Interesting. A reasonable LCD or OLED screen with similar dimensions to the original, adjusting the size of the interface would be amazing.

@morcibacsi On a different note, will ESP32-S3 zero built on the v1.5 board work? Is it possible to write to the VAN using the software itself or maybe a shield with mcp2515? I see board s3 in config.h, that's why I'm asking.

morcibacsi, 2025-02-26:
@bronisMateusz  thanks for the offer, but I have several of those displays, there are a few which works quite good and there are a few which are total garbage, so I can experiment with them.
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
morcibacsi, 2025-02-27:
Well that is very unfortunate. I only read the SDK which states that the S3 supports the legacy C macro mode of ULP here: https://docs.espressif.com/projects/esp-idf/en/stable/esp32s3/api-reference/system/ulp.html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

But according to this: https://github.com/boarchuz/HULP/issues/29 the used library HULP doesn't support the S3. The suggestion is to use the RISC-V core. Now the problem with the RISC-V core is that it can't be programmed from Arduino as I understand. At least it is the case with the ESP32-C6 according to this issue: https://github.com/espressif/arduino-esp32/issues/9721 It can be only programmed through esp-idf.

I tried searching for programming the S3 ULP from Arduino but I got only results with the C macros. So I assume the situation is the same as with the C6 - RISC-V can't be used from Arduino.

So the whole VAN-CAN bridge needs to be rewritten in esp-idf without using Arduino. And that is why I am rewriting the entire app as I mentioned here: https://github.com/morcibacsi/PSAVanCanBridgeHW/issues/8#issuecomment-2683456796 When I have finished it I think it could work with the S3 as well (but who knows?)

So the TL;DR is: as I see there are two options to support VAN bus writing with the S3 without the TSS:

1. rewrite the ULP VAN TX library to not use the HULP library - this way it can be compiled with the legacy macro API for the ESP32 and the S3. This means the application can be compiled with Arduino
2. rewrite everything to not use the Arduino framework so the RISC-V processor can be used with the C api. This way only the S3 and C6 will be supported and ESP32 support will be gone

Oh and to answer your question: if you would like to use the 1.5 board without the ULP stuff then you need to use the SPI shield with a TSS, and the code needs to be modified (preferably by adding a new board type and some ifdefs to exclude the ULP related libraries in that case). Or rewrite the ULP stuff to not use HULP but only the legacy macros.

godlespawel1, 2025-03-01:
Today I installed rev 1.5 soft on esp32 devkit v1 , two sn65hvd230 transceivers - I wanted to avoid installing a logic shifter which I did not have. Works without original display. RT3 unit. However, there are some problems - the steering wheel remote control does not work as in previous versions. In general, this control does not work with any other display, even original, other than Siemens. As in the previous version, after the car goes to sleep, the radio turns on for a moment with an error and then turns off. I have no idea how to fix this. Apart from that, everything is OK, error messages, open door, fuel consumption, etc., the car functions also show ECU errors and so on, and so do the sensors.

morcibacsi, 2025-03-01:
You can use 5V logic level with the esp32, my 1.5 board doesn't have any. Regarding the problems: there software generates a wifi hotspot which you can use to set up various things. Did you make any adjustments there?

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

godlespawel1, 2025-03-01:
Since ESP32 can work with 5v logic, I will build the next bridge on the TJA1050, I was actually in the process of assembling them when I realized that I didn't have a shifter. Yes, I changed the settings in the application - great. I turned on the remote control option and com2000, but nothing happened. I bridged some of the other options, but the control does not work. From what I remember from Sedre, the steering wheel remote control is connected directly to the original Siemens display and not to the VAN. But I'm not sure now. This is quite a strange problem, I tried with several original displays under the van and none of them wanted to work. Coming back to the application, I didn't really know which radio to choose, so I chose rt6. If you want, you can give me a little tip on how to make some logs and I'll post them here. The remote control is exactly as in the picture

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

morcibacsi, 2025-03-02:
I am not familiar with the 607, but checked the wiring diagram, I guess this is what you meant, that the remote controller is attached to the display:

8413: I think this is the remote
7215: display

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

When you install the V2C did you remove the Siemens display? If yes, then try reattaching it. Maybe the display is translating the signal of the remote control to VAN frames. You can check this by reconnecting the Siemens display. On the serial output all VAN frames are printed, so you can check if a frame presents which starts with 0E 9C (example: 0E 9C 4C 00 80 D4 E2)

By the way which radio do you have installed?

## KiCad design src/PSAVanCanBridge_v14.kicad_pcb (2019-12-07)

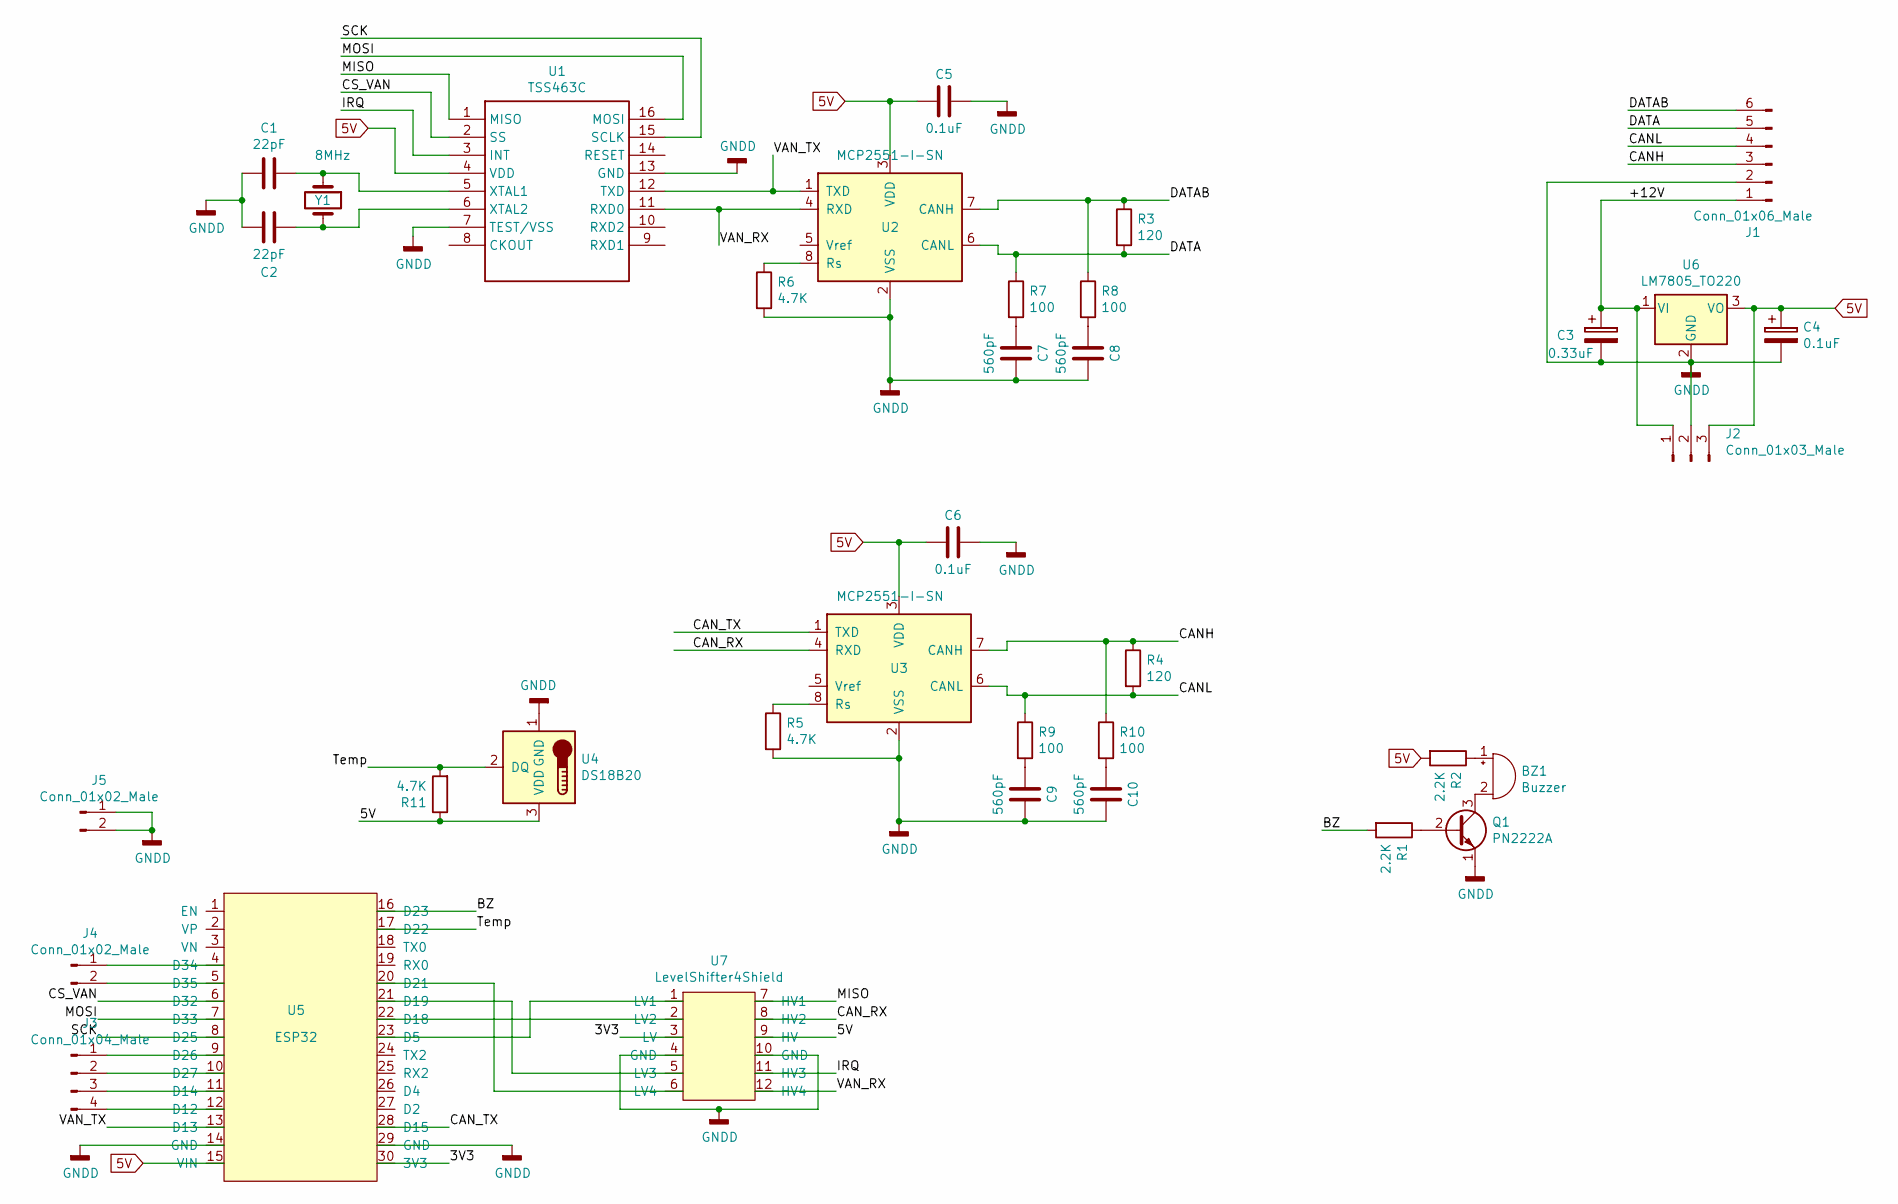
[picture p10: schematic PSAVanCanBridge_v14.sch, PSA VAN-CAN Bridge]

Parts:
BZ1: Buzzer; MagneticBuzzer_Kingstate_KCG0601
C1, C2: 22pF; C_1206_3216Metric_Pad1.42x1.75mm_HandSolder
C3: 0.33uF; CP_Radial_D4.0mm_P2.00mm
C4: 0.1uF; CP_Radial_D4.0mm_P2.00mm
C5, C6: 0.1uF; C_1206_3216Metric_Pad1.42x1.75mm_HandSolder
C7, C8, C9, C10: 560pF; C_1206_3216Metric_Pad1.42x1.75mm_HandSolder
J1: Conn_01x06_Male; JST_EH_S06B-EH_1x06_P2.50mm_Horizontal
J2: Conn_01x03_Male; PinSocket_1x03_P2.54mm_Vertical
J3: Conn_01x04_Male; PinHeader_1x04_P2.54mm_Vertical
J4, J5: Conn_01x02_Male; PinHeader_1x02_P2.54mm_Vertical
Q1: PN2222A; TO-92_Inline
R1, R2: 2.2K; R_1206_3216Metric_Pad1.42x1.75mm_HandSolder
R3, R4: 120; R_1206_3216Metric_Pad1.42x1.75mm_HandSolder
R5, R6, R11: 4.7K; R_1206_3216Metric_Pad1.42x1.75mm_HandSolder
R7, R8, R9, R10: 100; R_1206_3216Metric_Pad1.42x1.75mm_HandSolder
U1: TSS463C; SO16L
U2, U3: MCP2551-I-SN; SOIC-8_3.9x4.9mm_P1.27mm
U4: DS18B20; TO-92_Inline
U5: ESP32; ESP32_shield
U6: LM7805_TO220; TO-252-2
U7: LevelShifter4Shield; LevelShifter4_shield
Y1: 8MHz; Crystal_HC49-4H_Vertical

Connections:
5V: C4.1, C5.2, C6.2, J2.3, R2.2, R11.1, U1.4 (VDD), U2.3 (VDD), U3.3 (VDD), U4.3 (VDD), U5.15 (VIN), U6.3 (VO), U7.9 (HV)
/3V3: U5.30 (3V3), U7.3 (LV)
/+12V: C3.1, J1.1, J2.1, U6.1 (VI)
/BZ: R1.2, U5.16 (D23)
/CANH: J1.3, R4.1, R10.1, U3.7 (CANH)
/CANL: J1.4, R4.2, R9.1, U3.6 (CANL)
/CAN_RX: U3.4 (RXD), U7.8 (HV2)
/CAN_TX: U3.1 (TXD), U5.28 (D15)
/CS_VAN: U1.2 (SS), U5.6 (D32)
/DATA: J1.5, R3.2, R7.1, U2.6 (CANL)
/DATAB: J1.6, R3.1, R8.1, U2.7 (CANH)
/IRQ: U1.3 (INT), U7.11 (HV3)
/MISO: U1.1 (MISO), U7.7 (HV1)
/MOSI: U1.16 (MOSI), U5.7 (D33)
/SCK: U1.15 (SCLK), U5.8 (D25)
/Temp: R11.2, U4.2 (DQ), U5.17 (D22)
/VAN_RX: U1.11 (RXD0), U2.4 (RXD), U7.12 (HV4)
/VAN_TX: U1.12 (TXD), U2.1 (TXD), U5.13 (D13)
GNDD: C1.2, C2.2, C3.2, C4.2, C5.1, C6.1, C7.1, C8.1, C9.1, C10.1, J1.2, J2.2, J5.1, J5.2, Q1.1 (E), R5.2, R6.2, U1.7 (TEST/VSS), U1.13 (GND), U2.2 (VSS), U3.2 (VSS), U4.1 (GND), U5.14 (GND), U5.29 (GND), U6.2 (GND), U7.4 (GND), U7.10 (GND)
unnamed: BZ1.1 (-), R2.1
unnamed: BZ1.2 (+), Q1.3 (C)
unnamed: C1.1, U1.5 (XTAL1), Y1.1
unnamed: C2.1, U1.6 (XTAL2), Y1.2
unnamed: C7.2, R7.2
unnamed: C8.2, R8.2
unnamed: C9.2, R9.2
unnamed: C10.2, R10.2
unnamed: J3.1, U5.9 (D26)
unnamed: J3.2, U5.10 (D27)
unnamed: J3.3, U5.11 (D14)
unnamed: J3.4, U5.12 (D12)
unnamed: J4.1, U5.4 (D34)
unnamed: J4.2, U5.5 (D35)
unnamed: Q1.2 (B), R1.1
unnamed: R5.1, U3.8 (Rs)
unnamed: R6.1, U2.8 (Rs)
unnamed: U5.20 (D21), U7.6 (LV4)
unnamed: U5.21 (D19), U7.5 (LV3)
unnamed: U5.22 (D18), U7.2 (LV2)
unnamed: U5.23 (D5), U7.1 (LV1)

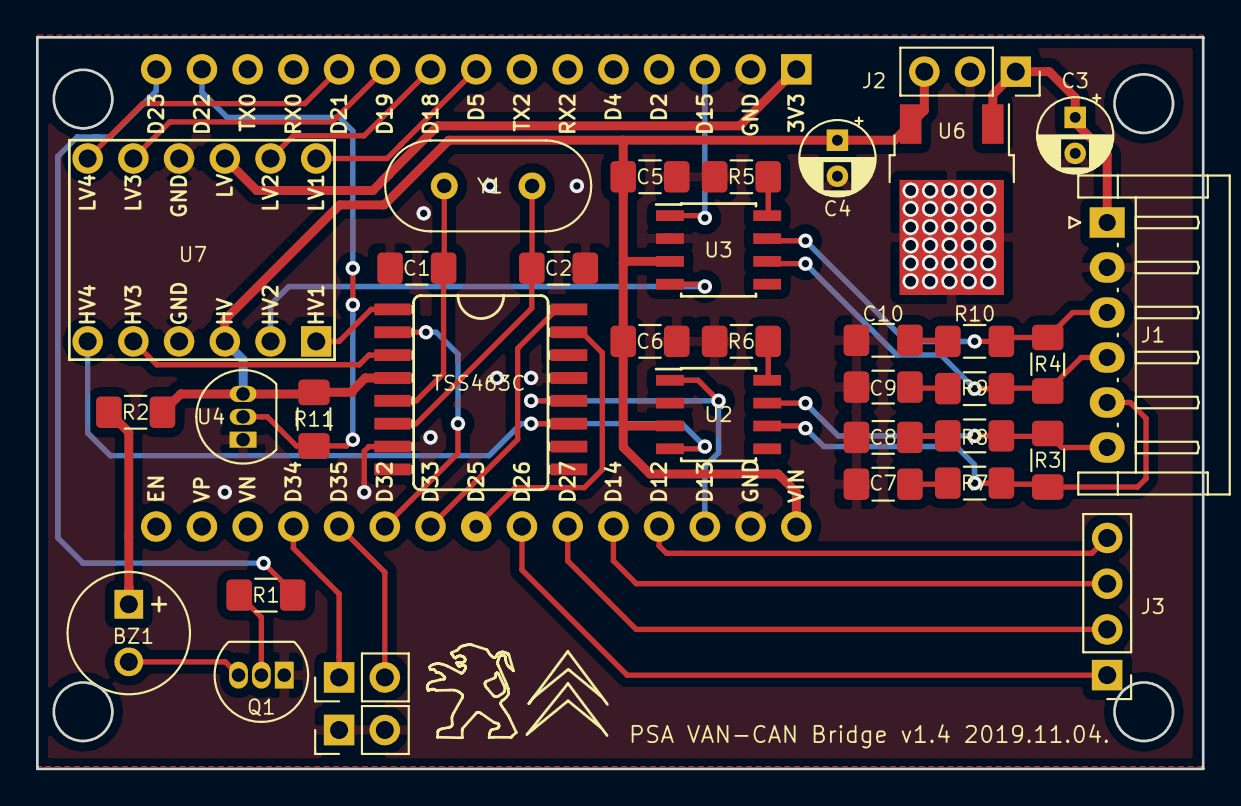
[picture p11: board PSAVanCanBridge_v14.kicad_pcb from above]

Board: 2 copper layers, 64.8 x 40.6 mm, 36 parts (0 on the bottom side), 40 nets.

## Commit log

2021-08-27 Fixed value of R5/R6 in the BOM of the full board
2023-11-14 First version of 3D printed case
    [body.stl, cap.stl]
